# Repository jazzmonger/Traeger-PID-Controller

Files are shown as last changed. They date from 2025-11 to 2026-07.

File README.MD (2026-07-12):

*4/15/25 - NOTE: project has been upgrade to an ESP32S3. Touch and display are just too much for the little D1. S3 handles it no problem.  New design files now uploaded to rev 2.2.0*

This project is for a generic ESP32 Based Traeger Pellet Smoker/Grill controller that can be used on any smoker/grill that has an auger, hotrod and fan used for control. Full Home Assistant control completes it and the sky is the limit on what can be done with it using automations.  See my ESPHome Forums post for discussions https://community.home-assistant.io/t/generic-traeger-smoker-grill-controller/867494



The inspiration for much of this project came from the excellent work done be @Nebhead and the PiSmoker project (https://github.com/nebhead/PiFire) based on the Raspberry Pi. Their Discord channel is here https://discord.com/channels/1027346882156052550/1027348991135985796

While I respect the platform for what it is, I'm not a huge Raspberry Pi fan and I wanted something based on an ESP32 and ESPHome that would integrate seamlessly into Home Assistant. So, this project was born.




Some key attributes of this scaled down version:

* its written in ESPHome, so its easy to understand and modify
* It can be used standalone or with Home Assistant
* it integrates seamlessly with Home Assistant and all functions are controllable via a LoveLace dashboard both on a PC and in the Home Assistant app.
* it emulates the existing new Trager controllers in all functions and adds several new functions
* it controls 1 auger, 1 hotrod & 1 fan found on the vast majority of pellet smokers
* it uses solid state relays for control
* it uses the existing PT1000 temperature sensor (can be adapted to a PT100)
* it adds a Smith-Predicting, PID temperature compensating control
* it controls the chamber temperature within approximately +/- 5F vs the +/- 25F for existing controllers
* rotary encoder support so you can control your grill temp with a spinny knob
* it has an interactive, touch screen ili9341 display
* it adds 3 optional configurable wired meat probes
* it allows dynamic configuration of ALL paramaters so it is infinitly tuneable to any pellet smoker
* it also allows for both touch screen control of all functions as well as optional individual buttons for control.
* it adds an optional VL53L0X Time of Flight (TOF) Sensor sensor to measure hopper pellet levels
* Circuit board for this scaled down version is exactly the same size as the Traeger controller allowing easy retrofit installation.

Outstanding temperature control even when opening the lid of the smoker.  Very little overshoot when adjusting temperatures (Smith Predictor).
Fully adjustable PID Params (advanced)
Lovelace Dashboards with animated icons for fans, auger & hotrod

Full architecture doc here https://github.com/jazzmonger/Traeger-PID-Controller/blob/main/doc/1Traeger-S3-operation-summary.md

This is a work in progress. I'm not affilaiated with Traeger or any other BBQ or smoker company. The design may or may not work with your gril, so, your mileage may vary. The chip Im using in this design is an ESP32 D1 Mini. Its small size,wide availability, and versatility makes it ideal for this use. You can probably use any ESP32 based dev board, but I cannot guarantee it will work. My larger project uses an ESP32-S3 as I needed every single available GPIO on that chip, and then some. Plus I needed to use the ESP-IDF framework for that project and also needed PSRAM, hence the S3 based board choice.

This project has been a ton of fun.  It's a couple thousand lines of ESPHome code so it's not a "beginner" project by any definition.  But if you study the code long enough, you'll begin to make sense of it all - that's what I love about ESPHome. It's easily approachable by novice users. 

Also, because this controller offers the ability to completely customize literally everything, it will take time for you to realize its full potential.  The PID tuning is especially complex, but after many days of testing, I've settled on PID value parameters that do a reasonable job of keeping the chamber temps within +/- 5F or so,  a far cry from the +/-25F of the current controllers. Adding the Smith Predictor to the PID controller eliminates overshoots from wide temperature changes. Many kudos must go to @dogtreatfairy for many hours spent helping me tune the PID controller.

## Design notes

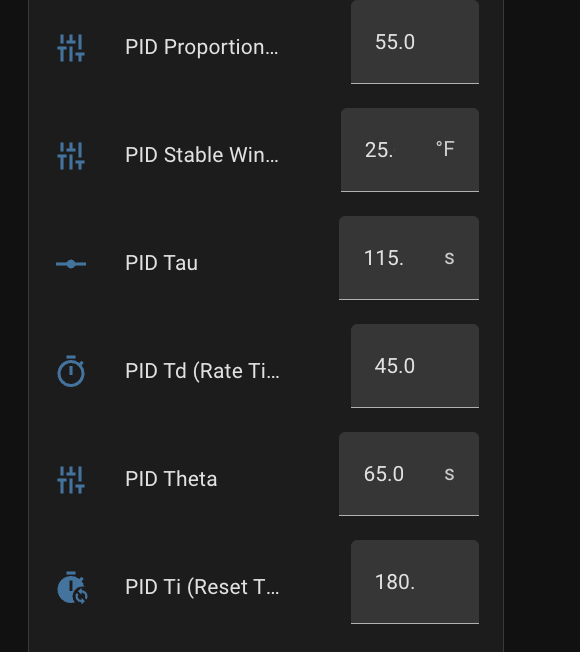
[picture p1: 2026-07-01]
PID defaults.png

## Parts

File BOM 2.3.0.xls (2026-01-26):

Reference | Value | Datasheet | Footprint | Qty | DNP
C1 | 100uf | ~ | Capacitor_THT:CP_Radial_D8.0mm_P3.50mm | 1
D1,D2,D7 | LED | ~ | LED_THT:LED_D3.0mm | 3
D9 | POWER ON LED | ~ | LED_THT:LED_D3.0mm | 1
Display1 | Conn_01x08_Socket | ~ | Connector_JST:JST_EH_B8B-EH-A_1x08_P2.50mm_Vertical | 1
F1 | 15A Mains | ~ | Fuse:Fuse Block 3544-2_KEYSTONE | 1
H1,H2,H3,H4 | MH | ~ | MountingHole:MountingHole_3.2mm_M3 | 4
J1 | MAX6675 | ~ | Connector_JST:JST_XH_B6B-XH-A_1x06_P2.50mm_Vertical | 1
J2 | Time of Flight Sensor | ~ | Connector_JST:JST_EH_B4B-EH-A_1x04_P2.50mm_Vertical | 1
J5 | Rotary Encoder | ~ | Connector_JST:JST_XH_B6B-XH-A_1x06_P2.50mm_Vertical | 1
J6 | ADS1115 0x49 | ~ | Connector_PinSocket_2.54mm:PinSocket_1x10_P2.54mm_Vertical | 1
J7,J8 | Temp Sensors | ~ | TerminalBlock_RND:TerminalBlock_RND_205-00014_1x04_P5.00mm_Horizontal | 2
J9,Touch1 | Conn_01x06_Socket | ~ | -- mixed values -- | 2
J10 | Buttons | ~ | Connector_JST:JST_XH_B6B-XH-A_1x06_P2.50mm_Vertical | 1
K1 | Fan SSR - OMRON G3MC-202PL |  | Relay_THT:RELAY_G3MB-202PDC5 | 1
K3 | Auger SSR - OMRON G3MC-202PL |  | Relay_THT:RELAY_G3MB-202PDC5 | 1
K6 | Igniter SSR - OMRON G3MC-202PL |  | Relay_THT:RELAY_G3MB-202PDC5 | 1
PS1 | HLK-PM01 | https://h.hlktech.com/download/ACDC%E7%94%B5%E6%BA%90%E6%A8%A1%E5%9D%973W%E7%B3%BB%E5%88%97/1/%E6%B5%B7%E5%87%8C%E7%A7%913W%E7%B3%BB%E5%88%97%E7%94%B5%E6%BA%9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 | Converter_ACDC:Converter_ACDC_Hi-Link_HLK-PMxx | 1
Q1,Q2,Q6 | BC547 | https://www.onsemi.com/pub/Collateral/BC550-D.pdf | Package_TO_SOT_THT:TO-92L_Inline | 3
R1,R3,R10 | 1k | ~ | Resistor_THT:R_Axial_DIN0207_L6.3mm_D2.5mm_P7.62mm_Horizontal | 3
R2,R6,R13 | 10K | ~ | Resistor_THT:R_Axial_DIN0207_L6.3mm_D2.5mm_P7.62mm_Horizontal | 3
R4,R5,R7,R8 | 150k | ~ | Resistor_THT:R_Axial_DIN0207_L6.3mm_D2.5mm_P7.62mm_Horizontal | 4
R15,R16,R21,R23 | 1K | ~ | Resistor_THT:R_Axial_DIN0207_L6.3mm_D2.5mm_P7.62mm_Horizontal | 4
U1 | ESP32-S3-DevKitC |  | PCM_Espressif:ESP32-S3-DevKitC | 1

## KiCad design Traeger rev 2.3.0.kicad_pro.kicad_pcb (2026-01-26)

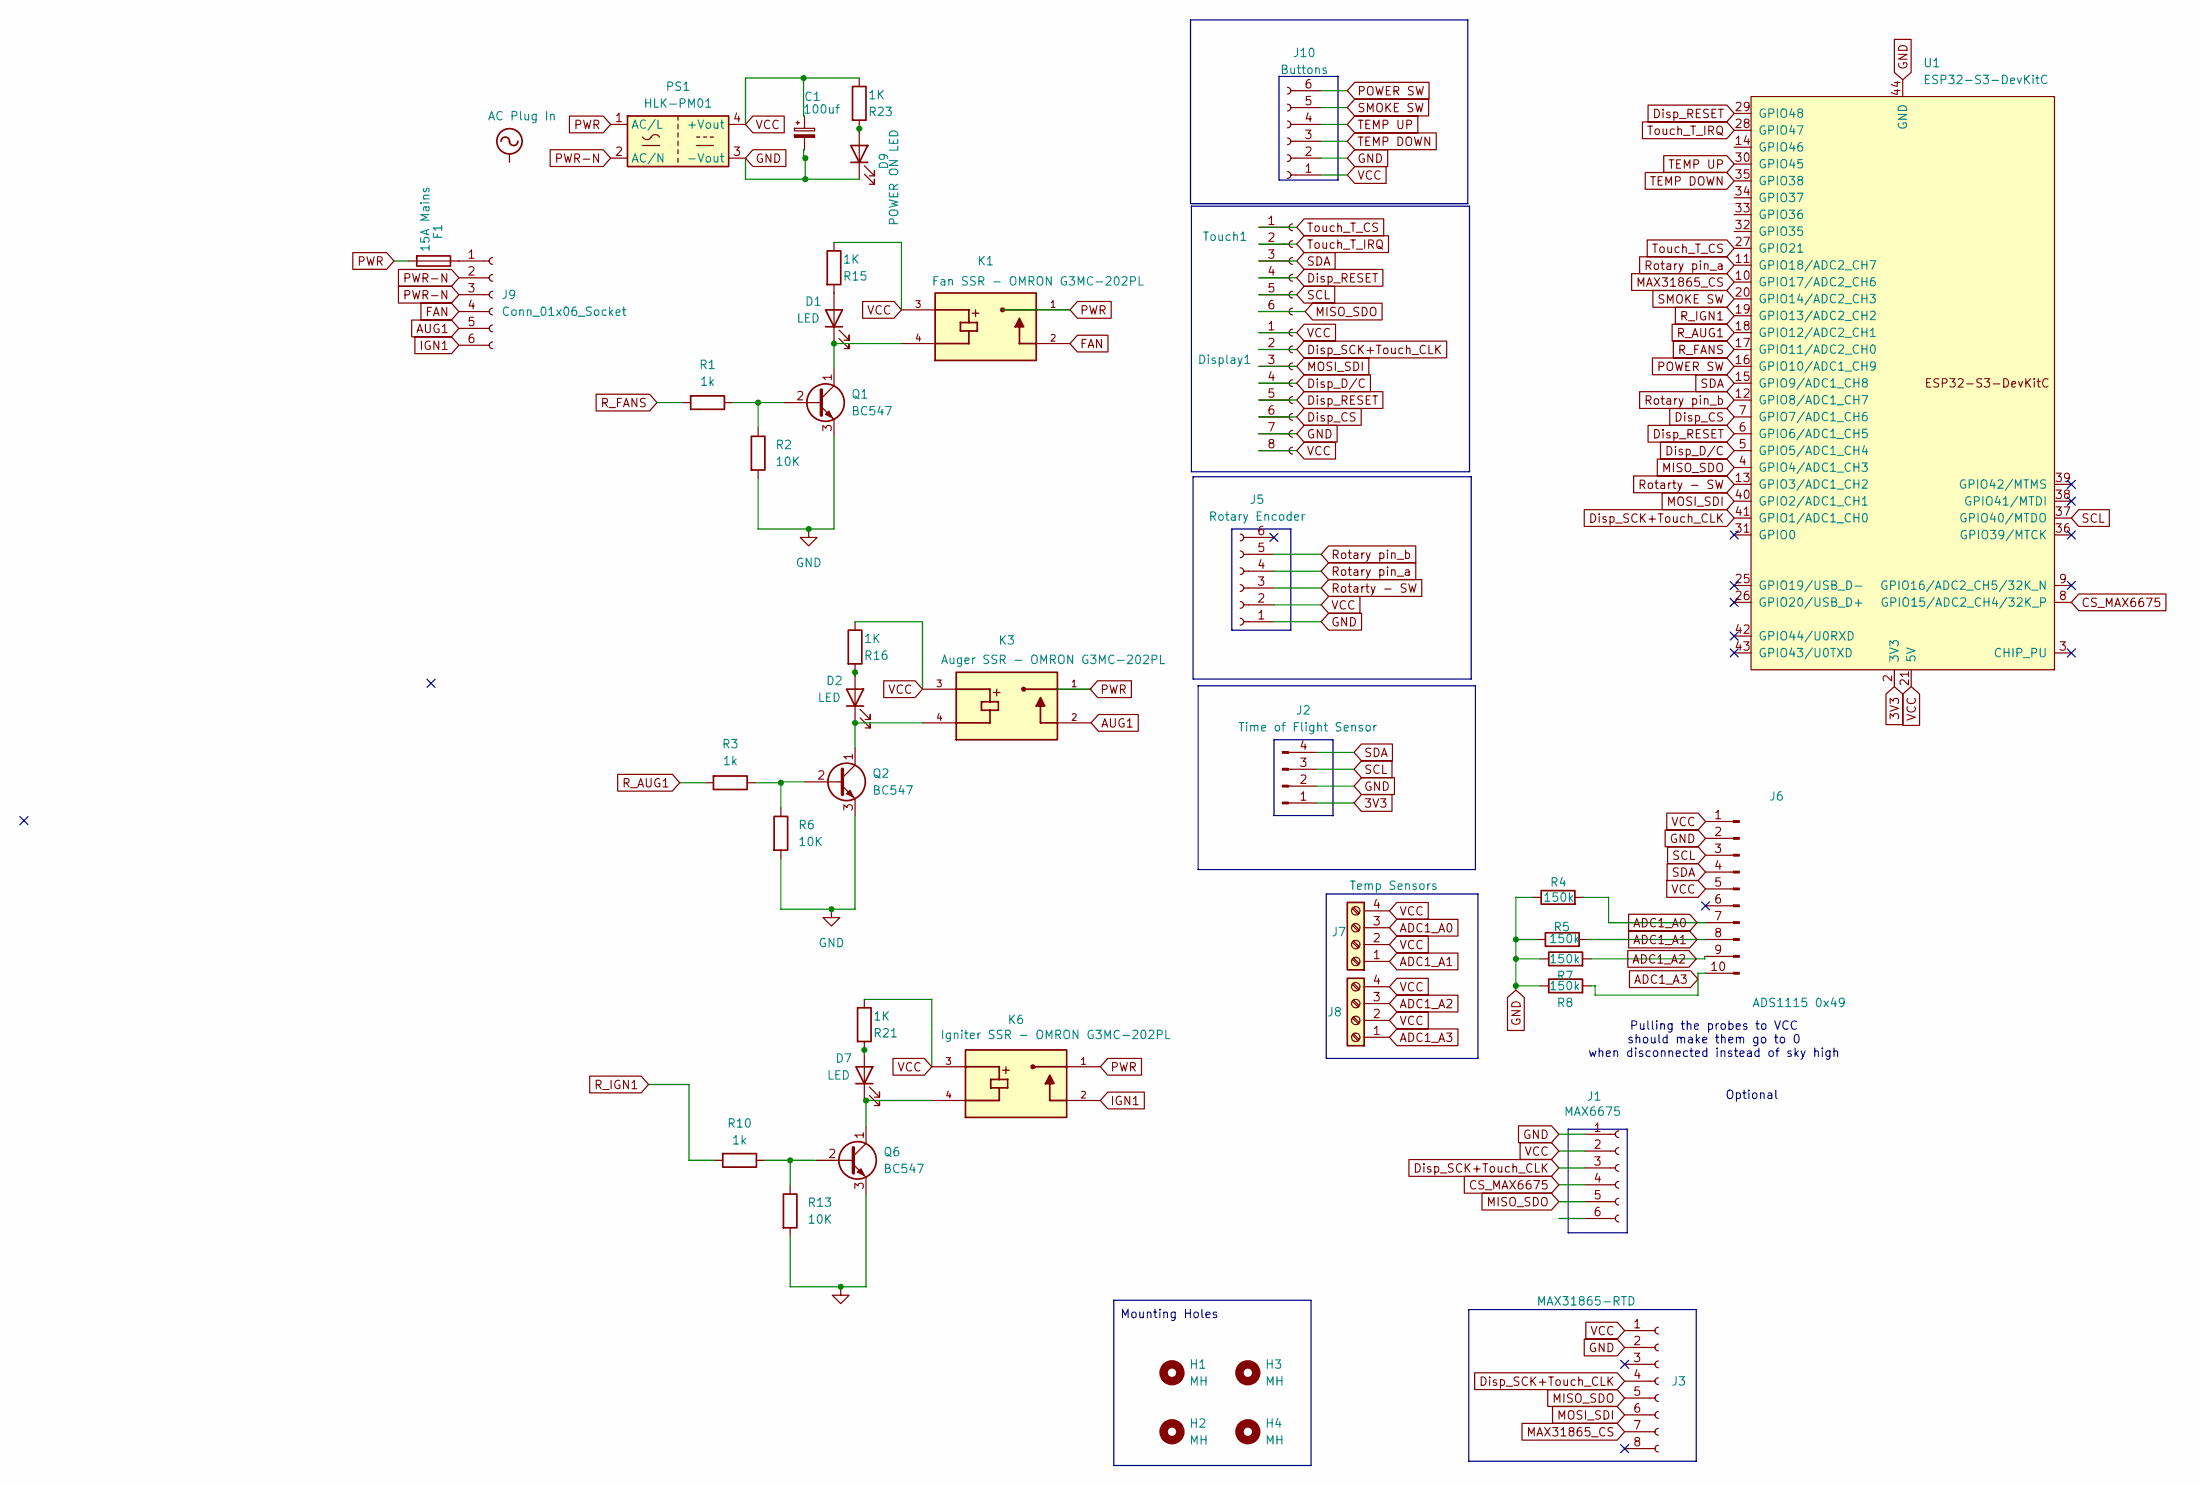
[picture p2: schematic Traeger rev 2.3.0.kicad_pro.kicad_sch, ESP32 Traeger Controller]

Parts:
C1: 100uf; CP_Radial_D8.0mm_P3.50mm
D1, D2, D7: LED; LED_D3.0mm
D9: POWER ON LED; LED_D3.0mm
Display1: Conn_01x08_Socket; JST_EH_B8B-EH-A_1x08_P2.50mm_Vertical
F1: 15A Mains; Fuse Block 3544-2_KEYSTONE
H1, H2, H3, H4: MH; MountingHole_3.2mm_M3
J1: MAX6675; JST_XH_B6B-XH-A_1x06_P2.50mm_Vertical
J2: Time of Flight Sensor; JST_EH_B4B-EH-A_1x04_P2.50mm_Vertical
J3: MAX31865-RTD; PinSocket_1x08_P2.54mm_Vertical
J5: Rotary Encoder; JST_XH_B6B-XH-A_1x06_P2.50mm_Vertical
J6: ADS1115 0x49; PinSocket_1x10_P2.54mm_Vertical
J7, J8: Temp Sensors; TerminalBlock_RND_205-00014_1x04_P5.00mm_Horizontal
J9: Conn_01x06_Socket; TerminalBlock_RND_205-00005_1x06_P5.00mm_Horizontal
J10: Buttons; JST_XH_B6B-XH-A_1x06_P2.50mm_Vertical
K1: Fan SSR - OMRON G3MC-202PL; RELAY_G3MB-202PDC5; PARTREV J091-E1-1A
K3: Auger SSR - OMRON G3MC-202PL; RELAY_G3MB-202PDC5; PARTREV J091-E1-1A
K6: Igniter SSR - OMRON G3MC-202PL; RELAY_G3MB-202PDC5; PARTREV J091-E1-1A
PS1: HLK-PM01; Converter_ACDC_Hi-Link_HLK-PMxx
Q1, Q2, Q6: BC547; TO-92L_Inline
R1, R3, R10: 1k; R_Axial_DIN0207_L6.3mm_D2.5mm_P7.62mm_Horizontal
R2, R6, R13: 10K; R_Axial_DIN0207_L6.3mm_D2.5mm_P7.62mm_Horizontal
R4, R5, R7, R8: 150k; R_Axial_DIN0207_L6.3mm_D2.5mm_P7.62mm_Horizontal
R15, R16, R21, R23: 1K; R_Axial_DIN0207_L6.3mm_D2.5mm_P7.62mm_Horizontal
Touch1: Conn_01x06_Socket; JST_EH_B6B-EH-A_1x06_P2.50mm_Vertical
U1: ESP32-S3-DevKitC

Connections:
3V3: J2.1, U1.1 (3V3), U1.2 (3V3)
ADC1_A0: J6.7, J7.3, R4.2
ADC1_A1: J6.8, J7.1, R5.2
ADC1_A2: J6.9, J8.3, R7.2
ADC1_A3: J6.10, J8.1, R8.2
AUG1: J9.5, K3.2
CS_MAX6675: J1.4, U1.8 (GPIO15/ADC2_CH4/32K_P)
Disp_CS: Display1.6, U1.7 (GPIO7/ADC1_CH6)
Disp_D/C: Display1.4, U1.5 (GPIO5/ADC1_CH4)
Disp_RESET: Display1.5, Touch1.4, U1.6 (GPIO6/ADC1_CH5), U1.29 (GPIO48)
Disp_SCK+Touch_CLK: Display1.2, J1.3, J3.4, U1.41 (GPIO1/ADC1_CH0)
FAN: J9.4, K1.2
GND: C1.2, D9.1 (K), Display1.7, J1.1, J2.2, J3.2, J5.1, J6.2, J10.2, PS1.3 (-Vout), Q1.3 (E), Q2.3 (E), Q6.3 (E), R2.2, R4.1, R5.1, R6.2, R7.1, R8.1, R13.2, U1.22 (GND), U1.23 (GND), U1.24 (GND), U1.44 (GND)
IGN1: J9.6, K6.2
MAX31865_CS: J3.7, U1.10 (GPIO17/ADC2_CH6)
MISO_SDO: J1.5, J3.5, Touch1.6, U1.4 (GPIO4/ADC1_CH3)
MOSI_SDI: Display1.3, J3.6, U1.40 (GPIO2/ADC1_CH1)
unnamed: D1.2 (A), R15.2
unnamed: D1.1 (K), K1.4, Q1.1 (C)
unnamed: D2.2 (A), R16.2
unnamed: D2.1 (K), K3.4, Q2.1 (C)
unnamed: D7.2 (A), R21.2
unnamed: D7.1 (K), K6.4, Q6.1 (C)
unnamed: D9.2 (A), R23.2
unnamed: F1.1, J9.1
unnamed: Q1.2 (B), R1.1, R2.1
unnamed: Q2.2 (B), R3.1, R6.1
unnamed: Q6.2 (B), R10.1, R13.1
POWER SW: J10.6, U1.16 (GPIO10/ADC1_CH9)
PWR: F1.2, K1.1, K3.1, K6.1, PS1.1 (AC/L)
PWR-N: J9.2, J9.3, PS1.2 (AC/N)
R_AUG1: R3.2, U1.18 (GPIO12/ADC2_CH1)
R_FANS: R1.2, U1.17 (GPIO11/ADC2_CH0)
R_IGN1: R10.2, U1.19 (GPIO13/ADC2_CH2)
Rotarty - SW: J5.3, U1.13 (GPIO3/ADC1_CH2)
Rotary pin_a: J5.4, U1.11 (GPIO18/ADC2_CH7)
Rotary pin_b: J5.5, U1.12 (GPIO8/ADC1_CH7)
SCL: J2.3, J6.3, Touch1.5, U1.37 (GPIO40/MTDO)
SDA: J2.4, J6.4, Touch1.3, U1.15 (GPIO9/ADC1_CH8)
SMOKE SW: J10.5, U1.20 (GPIO14/ADC2_CH3)
TEMP DOWN: J10.3, U1.35 (GPIO38)
TEMP UP: J10.4, U1.30 (GPIO45)
Touch_T_CS: Touch1.1, U1.27 (GPIO21)
Touch_T_IRQ: Touch1.2, U1.28 (GPIO47)
VCC: C1.1, Display1.1, Display1.8, J1.2, J3.1, J5.2, J6.1, J6.5, J7.2, J7.4, J8.2, J8.4, J10.1, K1.3, K3.3, K6.3, PS1.4 (+Vout), R15.1, R16.1, R21.1, R23.1, U1.21 (5V)

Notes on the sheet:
Pulling the probes to VCC should make them go to 0 when disconnected instead of sky high
Optional
Mounting Holes

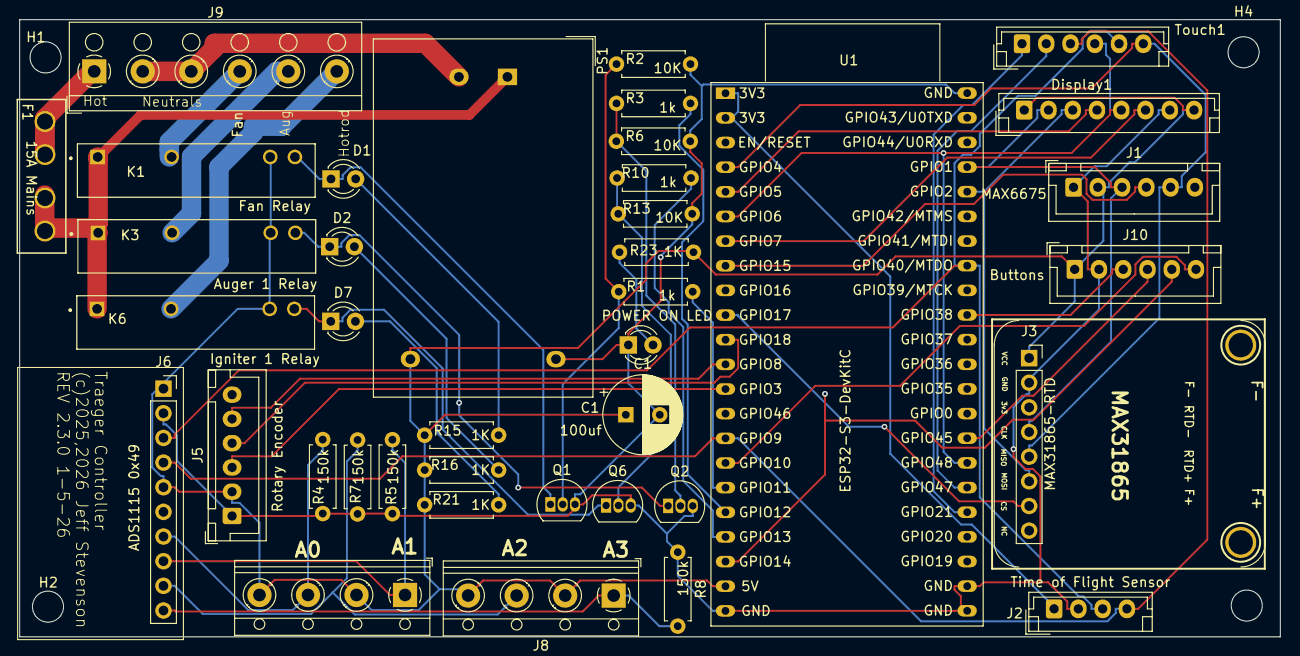
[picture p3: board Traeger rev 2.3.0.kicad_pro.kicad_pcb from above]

Board: 2 copper layers, 129.9 x 63.6 mm, 45 parts (0 on the bottom side), 45 nets.

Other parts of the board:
U$18, U$19: MOUNTINGHOLE2.5; MOUNTINGHOLE_2.5_PLATED

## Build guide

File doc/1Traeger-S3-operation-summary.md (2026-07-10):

# Traeger Smoker Controller — Operation Summary

**Device:** `1-traeger-smoker` (ESP32-S3)  
**Config:** `1Traeger-S3.yaml`  
**Platform:** ESPHome firmware with local touchscreen UI, WiFi, API, and OTA

This controller replaces stock Traeger electronics. It manages pellet ignition, auger feed, hot rod, fans, and chamber temperature using a custom Smith-predictor PID loop tuned for pellet smokers.

---

## System Overview

The smoker runs as a **state machine** driven by the **System ON/OFF** (`go`) switch. When turned on, it lights the fire pot (temperature-gated), then enters either **Heating Mode** (PID temperature control) or **Smoking Mode** (low-temp auger cycling). A **Firepot Monitor** watches firepot temperature after lighting and can re-ignite the hot rod if the flame dies.

```
Power ON → Light Fire Pot → Heating Mode (default)
                              ↓ toggle Smoke Mode
                           Smoking Mode
Power OFF → Stop all → Cooldown fans (if chamber > 175°F)
```

---

## Hardware & Sensors

| Component | Purpose |
|---|---|
| **MAX31865 RTD** (GPIO17) | Primary chamber temperature — drives PID control |
| **MAX6675 thermocouple** (GPIO15) | Firepot temperature — ignition & flame monitoring |
| **ADS1115 + thermistor** (A1) | Secondary temperature probe (A1) |
| **Rotary encoder** (GPIO8/18) | Adjust set temp or P-level |
| **ILI9341 touchscreen** (240×320) | Local display and touch controls |
| **GPIO outputs** | Fans (GPIO11), Auger (GPIO12), Hot Rod (GPIO13) |
| **GPIO inputs** | Power (GPIO10), Smoke (GPIO14), Temp Up/Down (GPIO45/38), Rotary push (GPIO3) |

**Temperature references (firepot, in °F equivalents):**

- Lighting complete: **300°F** (148.9°C)
- Heating mode hot rod on/off: **300°F / 325°F**
- Smoking mode hot rod on/off: **160°F / 200°F**
- Fan cooldown threshold: **175°F** (chamber RTD)

---

## Key Features

### 1. Automatic Fire Pot Lighting

On system start:

1. Hot rod and auger turn **ON**
2. Auger runs for **Pot lighting ON Time** (default 60s) to load pellets
3. Controller waits until firepot reaches **300°F**, up to **Pot lighting OFF Time** (default 600s)
4. If not lit in time: up to **3 retry** auger pulses (30s on / 30s off)
5. On success → **"Pot Lit"** → enters Heating Mode (hot rod stays on ~5 min, then firepot monitor takes over)
6. On failure → touchscreen dialog: *"Lighting failed, are pellets loaded?"* → system turns OFF; tap **OK** to dismiss

### 2. PID Temperature Control (Heating Mode)

- Runs during heating cycles when system is ON, smoke mode is OFF, and lighting is complete
- Uses chamber RTD vs. **Smoker Set Temperature** (140–550°F, default 225°F)
- Smith-predictor PID with:
  - Predictive error (rate-of-change + tau/theta lookahead)
  - Anti-windup and output clamping (5–80%)
  - Overshoot cutoff via **PID Stable Window**
- PID output maps to **auger ON/OFF duty cycle** within a 15s cycle
- All PID parameters exposed to Home Assistant for tuning

**Default PID tune (validated 2026-07-09 @ 225°F):** Pb=60, Ti=150, Td=40, tau=115, theta=25, center=0.001, stable_window=10

### 3. Smoking Mode

- Toggle via physical button, touchscreen, or HA switch (only effective when system ON)
- Turns **off** hot rod; stops lighting script
- Runs fixed **auger pulse cycle** instead of PID:
  - ON time: 10s (default)
  - OFF time: set by **P Select** (P0–P5 → 40–90s off times)
- Lower firepot hot-rod thresholds (160°F / 200°F) for gentle smoldering

### 4. P Select (Smoke Intensity)

Six presets (P0–P5) control smoke auger off-time:

| Level | Auger OFF time |
|---|---|
| P0 | 40s |
| P1 | 50s |
| P2 | 60s |
| P3 | 70s |
| P4 | 80s |
| P5 | 90s |

Auger ON time stays at 10s for all levels. Adjust via rotary encoder (when in P-setting mode) or Home Assistant.

### 5. Firepot Flame Recovery

Every **10 seconds**, if system is running and lighting is complete (`lighting_flag_global` false):

- If firepot temp drops below threshold → hot rod **ON** (flame recovery)
- If firepot temp rises above upper threshold → hot rod **OFF**

Ignition owns the hot rod while lighting is in progress.

### 6. Fan Management

- Fans turn **ON** at system start and during smoking mode
- On system OFF, if chamber > **175°F**:
  - `sc_shutdown` keeps fans on for **20 minutes** (1200s), then rechecks
  - Repeats until chamber ≤ 175°F
- Manual fan off while system is still ON and hot also starts cooldown
- Boot: if chamber already hot, fans start immediately

### 7. Local Display

- **Heat** / **Smoke** virtual buttons (green/blue when active)
- Set temp vs. RTD temp (large digits)
- Animated fan icon when auger runs
- Hot rod indicator (red bar when on)
- Current P-level display
- Status bar at bottom (mode messages, errors)
- Lighting-failed modal with OK dismiss

### 8. Emergency Stop

`Emergency Stop` button (`sc_stop_all_smoking`):

- Stops all scripts (lighting, heating, smoking)
- Turns off hot rod and auger immediately

---

## User Controls

| Control | Action |
|---|---|
| **Power button** (GPIO10 / touchscreen) | Toggle System ON/OFF |
| **Smoke button** (GPIO14 / touchscreen) | Toggle Smoking Mode (only when system ON) |
| **Temp Up/Down** (GPIO45/38) | Adjust set temp or P-level (shared with rotary logic) |
| **Rotary encoder** | Adjust set temp (5°F fine ≤225°F; 25°F coarse above; 5°F if rotary pressed) or P-level |
| **Rotary click** | Toggle between adjusting **Temp** vs. **P Level** |
| **Touch Hot Rod** | Manual hot rod toggle (diagnostic/override) |
| **Touch OK** (lighting dialog) | Dismiss lighting-failed dialog |

---

## Operating Sequence (Typical Cook)

1. **Load pellets**, set desired temperature (default 225°F)
2. **Press Power** → status: *"Lighting Fire Pot"*
3. Hot rod + auger run until firepot hits 300°F (or failure dialog)
4. **Heating Mode** begins — PID modulates auger to reach setpoint
5. Optional: **Press Smoke** for low-and-slow smoldering (PID disabled)
6. **Press Power to stop** → auger/hot rod off → fans run cooldown if still hot

---

## Home Assistant Integration

Exposed entities include:

- **Switches:** System ON/OFF, Smoking Mode, Fans, Auger, Hot Rod
- **Sensors:** RTD Temp, Firepot Temp, A1 Temp, PID diagnostics, Lighting Flag
- **Numbers:** Set temp, all PID tuning params, auger timing, lighting times
- **Select:** P Select (P0–P5)
- **Text:** Status Message
- **Buttons:** Emergency Stop, Controller Restart

WiFi connects with fast_connect; OTA and 24h API reboot timeout enabled. Logger defaults to INFO (no unauthenticated web server).

---

## Safety Behaviors

- Hot rod and auger restore **ALWAYS_OFF** on reboot
- System OFF immediately stops auger and hot rod via `sc_stop_all_smoking`
- Lighting failure shows blocking dialog until user acknowledges
- Fan cooldown on system OFF when chamber is still hot
- Invalid RTD readings are filtered (NAN) and skipped by PID

---

## Configurable Parameters (Highlights)

| Parameter | Default | Range |
|---|---|---|
| Smoker Set Temperature | 225°F | 140–550°F |
| PID Cycle Time | 15s | fixed in firmware |
| Auger Heating ON/OFF | 15s / 1s | PID-adjusted in heating mode |
| Smoke ON/OFF | 10s / 40s | 5–20s / 5–90s |
| Pot Lighting ON Time | 60s | 1–120s |
| Pot Lighting OFF Time | 600s | 60–600s |
| Fan Shutdown Delay | 1200s (20 min) | fixed |

---

## Summary

Full-featured pellet smoker controller: temperature-gated ignition with failure dialog, predictive PID for stable cooks, dedicated smoke mode with P-level presets, flame recovery after lighting, and safe cooldown — controllable on the touchscreen or via Home Assistant.

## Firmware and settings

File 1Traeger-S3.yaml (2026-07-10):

# Traeger S3 smoker controller
# PID defaults (2026-07-09 cook): Pb=60 Ti=150 Td=40 tau=115 theta=25 center=0.001 stable_window=10

esphome:
  name: 1-traeger-smoker
  friendly_name: 1 Traeger Smoker
  platformio_options:
    board_build.flash_mode: dio 
  on_boot:
    priority: -100
    then:
      - lambda: id(status_msg).publish_state("Ready");
      - if:
          condition:
            lambda: |-
              float temp = id(rtd_temperature_f).state;
              return !isnan(temp) && temp > 175.0;
          then:
            - switch.turn_on: fans_on_off_sw
            - lambda: id(status_msg).publish_state("Hot startup - Fans ON");
          else:
            - switch.turn_off: fans_on_off_sw
            - lambda: id(status_msg).publish_state("Ready!");
      # ILI9341 often wakes blank until rails settle; re-init a few seconds later
      - delay: 3s
      - script.execute: sc_tft_reinit
packages:
    touchscreen: !include common/IPS4.0_touchscreen_(esp32S3_Trager_1pot).yaml
    display_ui: !include common/1Traeger-S3_display.yaml

psram:
  mode: octal
  speed: 80MHz
esp32:
  board: esp32-s3-devkitc-1
  variant: esp32s3
  flash_size: 16MB
  framework:
    type: arduino

api:
  reboot_timeout: 24h
logger:
    level: INFO
    logs:
      component: none
      api.connection: ERROR
      max31865: WARN
      max6675: WARN
      ads1115.sensor: ERROR
      sensor: ERROR 
      number: ERROR
      ili9xxx: ERROR
      FT63X6: ERROR
      ft63x6: WARN
      spi: ERROR
      touchscreen: ERROR
      I2C: ERROR
      esp-idf: WARN

ota:
  - platform: esphome
wifi:
  ssid: !secret wifi_ssid
  password: !secret wifi_password
  fast_connect: true

spi:
  - id: spi_bus
    clk_pin: GPIO1 #display SCK/touch T_CLK
    mosi_pin: GPIO2 #SDI-max / display /touch T_DIN
    miso_pin: GPIO4 #SDO-max / touch T_DO, display doesnt need MISO

display:
  - id: !extend mydisplay
    platform: ili9xxx
    spi_id: spi_bus
    data_rate: 20MHz
    model: ILI9341 #TFT 2.4
    dc_pin: GPIO5
    cs_pin: GPIO7
    reset_pin: GPIO6
    color_palette: 8BIT
    #LED - jumper to VCC so it is always on
    rotation: 0
    invert_colors: true
    show_test_card: false



globals:
  - id: p_select_index_global
    type: int
    restore_value: yes

  - id: lighting_flag_global
    type: bool
    restore_value: no
    initial_value: 'true'

  - id: lighting_failed_dialog
    type: bool
    restore_value: no
    initial_value: 'false'

  - id: lighting_start_ms
    type: unsigned long
    restore_value: no
    initial_value: '0'

  - id: lighting_retry_count
    type: int
    restore_value: no
    initial_value: '0'

  - id: page_1_selected_option
    type: std::string
    restore_value: no
    initial_value: '"temp_setting"'

select:         
  - platform: template
    name: "P Select"
    id: p_select
    options:
      - "P0"
      - "P1"
      - "P2"
      - "P3"
      - "P4"
      - "P5"
    initial_option: "P0"
    restore_value: true
    optimistic: true
    set_action:
      - logger.log:
          format: "Chosen option: %s"
          args: ["x.c_str()"]      
    on_value: #set smoke times
      - lambda: |-
          id(p_select_index_global) = i;
          switch(i) {
            case 0: id(smoke_off_time).publish_state(40); id(smoke_on_time).publish_state(10);  break;
            case 1: id(smoke_off_time).publish_state(50); id(smoke_on_time).publish_state(10);  break;
            case 2: id(smoke_off_time).publish_state(60); id(smoke_on_time).publish_state(10);  break;
            case 3: id(smoke_off_time).publish_state(70); id(smoke_on_time).publish_state(10);  break;
            case 4: id(smoke_off_time).publish_state(80); id(smoke_on_time).publish_state(10);  break;
            case 5: id(smoke_off_time).publish_state(90); id(smoke_on_time).publish_state(10);  break;
          }
i2c: 
  - id:  i2c_bus
    sda: GPIO9
    scl: GPIO40
    scan: true
    timeout: 100ms
    frequency: 50kHz

ads1115:
  address: 0x48
  id: ads1115_48
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

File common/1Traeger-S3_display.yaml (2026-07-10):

# Shared Traeger smoker UI (lambda + fonts). Hardware/sim YAML extends mydisplay.
display:
  - id: mydisplay
    update_interval: 0.5s
    lambda: |-
       auto black = Color(0, 0, 0);
       auto red = Color(255, 0, 0);
       auto green = Color(0, 255, 0);
       auto blue = Color(0, 0, 255);
       auto white = Color(255, 255, 255);
       auto grey = Color(120, 120, 120);

       if (id(lighting_failed_dialog)) {
         it.filled_rectangle(0, 0, 240, 320, Color(0, 0, 0));
         it.filled_rectangle(8, 70, 224, 190, Color(30, 30, 30));
         it.rectangle(8, 70, 224, 190, red);
         auto msg_color = ((millis() / 500) % 2 == 0) ? red : white;
         it.print(18, 95, id(font20), msg_color, "Lighting failed,");
         it.print(18, 120, id(font20), msg_color, "are pellets loaded?");
         it.filled_rectangle(70, 210, 100, 40, Color(0, 140, 0));
         it.rectangle(70, 210, 100, 40, white);
         it.print(100, 218, id(font30), white, "OK");
         return;
       }

       //Status msg
        it.filled_rectangle(0, 295, 230, 26, Color(80, 80, 80)); // Grey background with padding
        it.print(1, 295, id(font20), id(status_msg).state.c_str());

        it.print(20, 1, id(font30), "Heat");
        it.print(130, 1, id(font30), "Smoke");
       // Power button
       if (id(go).state && !id(smoke_mode).state) {
         // Active state - bright green with 3D effect
         it.filled_rectangle(40, 40, 30, 42, Color(0, 200, 0));  // Main button
         it.filled_rectangle(40, 38, 30, 2, Color(0, 255, 0));   // Highlight
         it.filled_rectangle(40, 82, 30, 2, Color(0, 100, 0));   // Shadow
         it.filled_rectangle(38, 40, 2, 42, Color(0, 255, 0));   // Left highlight
         it.filled_rectangle(70, 40, 2, 42, Color(0, 100, 0));   // Right shadow
       } else {
         // Inactive state - dark gray with 3D effect
         it.filled_rectangle(40, 40, 30, 42, Color(80, 80, 80)); // Main button
         it.filled_rectangle(40, 38, 30, 2, Color(120, 120, 120)); // Highlight
         it.filled_rectangle(40, 82, 30, 2, Color(40, 40, 40));    // Shadow
         it.filled_rectangle(38, 40, 2, 42, Color(120, 120, 120)); // Left highlight
         it.filled_rectangle(70, 40, 2, 42, Color(40, 40, 40));    // Right shadow
       }
       // Smoke button
       if (id(smoke_mode).state) {
         // Active state - bright blue with 3D effect
         it.filled_rectangle(160, 40, 30, 42, Color(0, 0, 200));  // Main button
         it.filled_rectangle(160, 38, 30, 2, Color(0, 0, 255));   // Highlight
         it.filled_rectangle(160, 82, 30, 2, Color(0, 0, 100));   // Shadow
         it.filled_rectangle(158, 40, 2, 42, Color(0, 0, 255));   // Left highlight
         it.filled_rectangle(190, 40, 2, 42, Color(0, 0, 100));   // Right shadow
       } else {
         // Inactive state - dark gray with 3D effect
         it.filled_rectangle(160, 40, 30, 42, Color(80, 80, 80)); // Main button
         it.filled_rectangle(160, 38, 30, 2, Color(120, 120, 120)); // Highlight
         it.filled_rectangle(160, 82, 30, 2, Color(40, 40, 40));    // Shadow
         it.filled_rectangle(158, 40, 2, 42, Color(120, 120, 120)); // Left highlight
         it.filled_rectangle(190, 40, 2, 42, Color(40, 40, 40));    // Right shadow
       }
       //smoker_set_temp on left
       it.print(20, 100, id(font20), "Set Temp");
       it.printf(20, 120, id(font45),  "%.0f°", id(smoker_set_temp).state);

       //a0_temperature on right
       it.print(130, 100, id(font20), "RTD Temp");
       it.printf(130, 120, id(font45), "%.0f°", id(rtd_temperature_f).state);

        // Y offset for positioning
        int y_offset = 180;

        // Draw main body of BBQ trailer
        it.rectangle(0, y_offset-5, 230, 115, blue);

        // FAN1 Draw animated fan when auger is running
        int cx = 205;
        if (id(auger_1_sw).state) {
          // Calculate rotation angle based on time
          float angle = fmod(millis() / 50.0, 360.0) * M_PI / 180.0;

          // FAN1 Center point
          int cy = y_offset + 20;
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

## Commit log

2025-03-22 KiCad files
    [Traeger rev 1.0.0.kicad_sch]
2025-03-31 Update Traeger rev 1.0.0.kicad_pro
2025-03-31 Update Traeger rev 1.0.0.kicad_sch
    [Traeger rev 1.0.0.kicad_sch]
2025-10-30 Create Trager BBQ KiCad files
2026-01-26 Final working circuit board v 2.3.0
    [BOM 2.3.0.xls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]
2026-03-25 New ESPhome config file using ESP32S3 chip
2026-07-01 Refactor Traeger S3 ESPHome config and fix PID steady-state error.
    Extract display and touchscreen into packages, add uv-based compile tooling, expose auger heating times to Home Assistant, and relax PID integral/output limits so setpoint can be reached.
    [1Traeger-S3.yaml, 1Traeger-S3_display.yaml]
2026-07-10 Harden Traeger S3 control logic and lock in validated PID tune.
    Temperature-gate ignition, fix cooldown/fan shutdown, clean dead code, and sync docs after cook tests at 225°F.
    [1Traeger-S3.yaml, 1Traeger-S3_display.yaml]
2026-07-10 Fix blank ILI9341 on cold boot with delayed display re-init.
    Restore reset_pin ownership to the driver and call setup() again after rails settle so the panel comes up without a second power cycle.
    [1Traeger-S3.yaml]
2026-07-10 Enhance Traeger S3 temperature sensor calibration and simplify conversion logic. Added linear calibration points for improved accuracy and removed polynomial calculation for temperature conversion.
2026-07-10 Refactor Traeger S3 temperature sensor calibration logic for improved accuracy. Introduced linear calibration points and eliminated polynomial calculations for temperature conversion.
2026-07-10 Update Traeger S3 temperature sensor calibration points for enhanced accuracy. Replaced existing calibration data with new linear values to improve sensor performance.
    [1Traeger-S3.yaml]

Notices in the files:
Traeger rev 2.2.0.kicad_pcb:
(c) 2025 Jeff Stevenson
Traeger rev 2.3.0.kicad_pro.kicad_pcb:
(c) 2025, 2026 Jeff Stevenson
